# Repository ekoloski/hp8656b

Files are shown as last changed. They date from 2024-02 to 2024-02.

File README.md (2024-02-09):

## HP1820-3618 replacement

This project aims to use modern hardware to recreate the functionality of a mask rom microcontroller known as 1820-3618 in HP catalogs. It was used in the HP 8656B Signal Generator, and possibly other equipment, to interface the generators main cpu with both the fractional-n divider asic and various modulation circuits. It's a serial to parallel converter that also manages some gpio control lines.

The service manual describes a high level overview of the chips functions but lacks enough detail to create a suitable replacement. As I later found out, this firmware also does a couple of interesting things in response to a few serial commands I've never seen my 8656B issue. It also provides some routines for troubleshooting the rest of the circuitry.

### But...why go to the effort when you can just get one from a junk unit?

I purchased this signal generator on one of the auction sites with the understanding that it was for parts only and needed repair. My goal from the start was to restore the unit and use it as part of my electronics lab. After quite a bit of debugging I ultimately traced the issues to a failing adjustment potentiometer and a failed transistor. This is where the story should happily end, however it does not. In the course of troubleshooting I did some sloppy probing around A13U9 which led to the introduction of **-15V** to the 'Out of Lock' comparator output pin, which is directly connected to pin 11 of the 1820-3618, A13U28.

The chip never functioned properly after that event. The unit was not able to achieve PLL lock even after the original faults were discovered and repaired. I probed the serial input of A13U28 and found data. I then probed the 4 parallel output pins and the control lines, still no activity.

I was unable to find any information on this chip, labeled as a Motorola SC87336CP. Comparing the pinout in the 8656B service manual I found it to be fairly unique pinout in the world of Motorola 8bit microcontrollers of the time. Some educated guesses led me to the MC68705P5, which fit the description. I suspect that my chip is a mask rom variant of this microprocessor. Which is great, but without the ability to read the ROM I am still stuck.

Thinking that it was a lost cause to recreate the chip at this point I decided to purchase a second 8656B in much worse cosmetic condition. The part was harvested, transplanted, and the repaired unit works great. Everything should have been wonderful! Unfortunately I decided to investigate what in addition to a missing A13U28 was wrong with the donor unit. Much to my disappointment, the only problem was a faulty electrolytic capacitor. Of course I had to replace it but now I'm back to the start and stuck with an otherwise functional boat anchor in need of one unobtanium chip.

### Extracting the ROM

After quite a bit of reading I had come to the belief that the chip would need to be carefully decapped and photographed under a microscope. It could then be possible to locate the ROM on the die and optically recover the bits. I've seen it done on the internet, so it's got to be easy, right?

Probably not. So I shelved this project in lieu of some others and spent a while just not thinking about it. Then I did a little more research and came across the work by [Sean Riddle](http://seanriddle.com/mc68705p5.html). He details an obscure operating mode of the same family of CPU, and how he exploited it.

This mode is entered by powering the chip with /RESET /INT and TIMER high, and pulling PC0 high to 7.5V. When the micro comes out of reset it will ingest opcodes to execute from PortA. At the same time, an output is latched onto PortB. If the instruction on PortA happens to be 0x9d (nop) then the chip will simply continue to iterate through all 2K of it's address space. The output on PortB is a permutation of the current address, and the contents in memory. There is also apparently some data on PortC, but that's damaged on my chip so I didn't bother. I suspect it's the missing bits of the address.

As mentioned, the damage to my chip was conveniently located on PortC. Maybe there's hope that this method works on my particular mask rom, and that it's not too badly damaged? I figured it's worth a shot, so I breadboarded everything up and hooked up the scope.

To my amazement, there was data. A stream of it! The byte is sampled on the falling edge of each clock, 8 clocks are required to produce one byte of actual data, as it appears in the form of:
    {ADDR} {ADDR} {DATA} {DATA} {ADDR} {ADDR} {DATA} {DATA}

I noticed that the pattern was repeating at each 16K boundary, meaning we have a 2K address space. The chip will happily loop through and read out the address space until reset.

A healthy chunk of data was captured on the logic analyzer. The data was sifted from the noise to produce a raw dump.

### Interpreting the ROM

Next I needed to figure out what I was looking at. Nothing lined up with the memory mapping from the MC68705P5's datasheet. I realized that not only did the chip fetch an opcode from PortA, it fetched an address. The 0x9D must have been read in as $59D, meaning my capture started at 1437 bytes in! I shifted the data to realign it and it lined up perfectly with the memory map in the datasheet. I overwrote all non-ROM addresses with 0x9D to make disassembly easier and was ready to disassemble.

The [MAME project](https://www.mamedev.org/) has done a lot of work with this type of micro, and it's no surprise they have a nice disassembler called unidasm, which happily ingested the ROM from my crippled chip.

It took a moment and help from the Motorola M68HC05 Applications Guide, but I was able to wrap my head around the result. The only code I've written for microprocessors has been interrupt driven and was written in C. This is neither of those things. Instead it's beautify simple and elegant.

Beyond that, recreating the functionality of the chip be considerably more difficult without it. There are nuances that are not discussed in the service manual. I've also found that a test pin labeled as unused in the service manual does have a routine associated with it. Perhaps this chip was used in other equipment?

### Converting to something more modern

Now that I have the program from the chip and it's datasheet there's no reason not to create a modern replacement.

I decided on an Atmel ATMEGA32U4-MUR. It was available, came in a small enough package that I could build a board to fit the original DIP-28W, and had more than enough capability for the job. After creating a small breakout board and soldering pin headers to emulate the original DIP28W, I was ready to start adapting the program.

With how purpose built the code is, and with the role it plays in setting up things like the FM calibration and other support circuitry in the 8656B, I suspect that the timings involved may be somewhat critical. I likely wouldn't achieve anything as close to the original if I wrote it in C, unless I did a bunch of extra work. So, AVR8 it is.

### Again...why?

The chances of anyone else needing a replacement for an HP1820-3618 are pretty slim. The chances of finding this and needing a replacement? Negligible.

But I would bet that there are others who may find themselves, for whatever reason, wanting to get a peek into a similar mask rom. I'd be glad if it helps in that case and maybe even resurrects some piece of hardware. It's been a lot of fun, and I've rediscovered a bit of code that, in all likelihood, no one else has even looked at in at least the last 25 years.

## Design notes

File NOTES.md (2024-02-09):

**8656B Notes**

## Clock considerations
The 68705P5 internal clock generator prescales the oscillator input by four. A 4MHz AT cut parallel resonance crystal at about 27pF is populated on the 8656B, meaning that the microcontroller will run at a clock frequency of 1MHz.

The 32U4 does have an internal prescaler on it's oscillator input, however this one is a divide-by-8. Fortunately most instructions run a little quicker in AVR so the timings are not too far off. Consideration should be taken when calculating delays.

## Fractional N Microprocessor
Various notes about this thing. In general it slurps up (up to) 17 bytes of serial information. It digests the first byte as a command and actuates a number of control lines in response. The main functionality is to convert this 16 bytes of data into 4 bit chunks spit out of it's parallel port.

### Serial Data Input
  - Serial data is sampled on rising edge of clock pulse and is sent in 4-bit words. Data always begins with a 4-bit command to this microcontroller. Commands are listed below. If the command is 0x8 or higher, 16 words of 4-bit data are expected to follow. 

### Serial Commands

The command is the first byte received on the serial line and directs the microprocessor to actuate
different modes on it's output. For example, enable FM mode.

  |Command|Description|
  |---|---|
  |0x00|Set `fm_dc_en` and update the controller ? |
  |0x01|Send status of PLL Out of Lock indicator, used in built-in self test mode `6` (Press Shift+INCR SET to enter test mode) |
  |0x02|Disable FM|
  |0x03|Enable FM|
  |0x04|Enable FM DC Mode|
  |0x05|FM Calibration Cycle|
  |0x08|Standard transmit - sends data to Fractional-N controller - last byte is a **0x04**|
  |0x09|Alternate transmit - last byte is a **0x08**|
  |0x0A|Alternate transmit - last byte is a **0x09**|

### Signals (Pin Registers as they are on the 68705P5)
  - PA0:3 Parallel Data Out
  - PA4 : Parallel Clock Out
  - PA5 : Data Valid Output
    - Typically a 7.2uS positive pulse, otherwise low
  - PA6 : FM DC Enable
  - PA7 : FM Offset
  - PB0 : FM Enable
  - PB1 : B+C (H) Blank/Compare Out
  - PB2 : S (L)
  - PB3 : FM Cal Add Cycle
  - PB4 : (Test Mode Input) FM No Calibration
  - PB5 : (Test Mode Input) LF Loop set to 66.80001MHz
  - PB6 : (Test Mode Input) Signal Analysis Test Mode
  - PB7 : (Test Mode Input) Unused
  - PC1 : Serial Data Input
  - PC2 : Mode Select Input
    - Normal operation: High
    - Test mode: Low
  - PC3 : PLL Out Of Lock Indicator
  - INT : Serial Clock In

### Signals (Pin Registers as they are on the 32U4)
  - PD0:3 Parallel Data Out
  - PD4 : Parallel Clock Out
  - PD5 : Data Valid Output
    - Typically a 7.2uS positive pulse, otherwise low
  - PD6 : FM DC Enable
  - PD7 : FM Offset
  - PB0 : FM Enable
  - PB1 : B+C (H) Blank/Compare Out
  - PB2 : S (L)
  - PB3 : FM Cal Add Cycle
  - PB4 : (Test Mode Input) FM No Calibration
  - PB5 : (Test Mode Input) LF Loop set to 66.80001MHz
  - PB6 : (Test Mode Input) Signal Analysis Test Mode
  - PB7 : (Test Mode Input) Unused
  - PF5 : Serial Data Input
  - PF6 : Mode Select Input
    - Normal operation: High
    - Test mode: Low
  - PF7 : PLL Out Of Lock Indicator
  - PC7 : Serial Clock In

### fuses:
  -  _lfuse_ **0xED** - Ext Crystal Osc, Freq 3.0-8.0MHz, 16KCK _ 4.1mS delay, /8 Divider
  -  _hfuse_ **0xD9** - Boot flash 2048, start $3800, JTAG disabled SPI Programming enabled
  -  _efuse_ **0xC8** - Brownout Detection 4.3V, HW Boot Enable=0
  -  _lock_  **0xFF** - No lock set

  - `avrdude -c dragon_isp -p m32u4 -P usb -U lfuse:w:0x6D:m`
  - `avrdude -c dragon_isp -p m32u4 -P usb -U hfuse:w:0xD9:m`
  - `avrdude -c dragon_isp -p m32u4 -P usb -U efuse:w:0xC8:m`
  - `avrdude -c dragon_isp -p m32u4 -P usb -U lock:w:0xFF:m`
  - `avrdude -c dragon_isp -p m32u4 -P usb -U flash:w:1820-3618.hex`

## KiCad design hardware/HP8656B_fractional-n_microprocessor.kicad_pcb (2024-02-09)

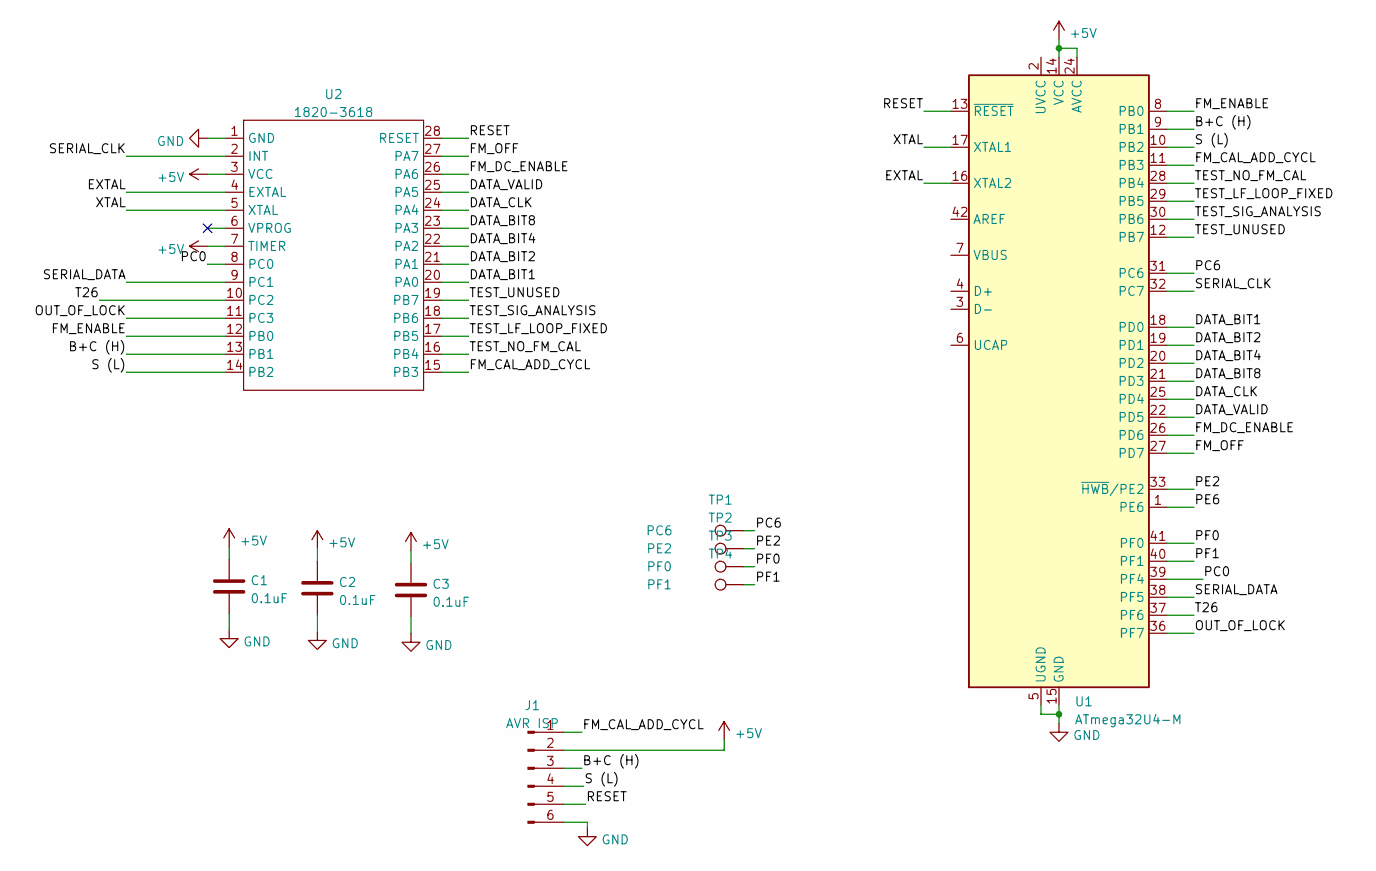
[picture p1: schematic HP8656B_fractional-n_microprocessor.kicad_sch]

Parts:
C1, C2, C3: 0.1uF; C_0603_1608Metric
J1: AVR ISP; PinHeader_2x03_P2.54mm_Vertical
TP1: PC6; TestPoint_Pad_D1.0mm
TP2: PE2; TestPoint_Pad_D1.0mm
TP3: PF0; TestPoint_Pad_D1.0mm
TP4: PF1; TestPoint_Pad_D1.0mm
U1: ATmega32U4-M; QFN-44-1EP_7x7mm_P0.5mm_EP5.2x5.2mm
U2: 1820-3618; DIP-28_W15.24mm_Socket

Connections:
+5V: C1.1, C2.1, C3.1, J1.2, U1.14 (VCC), U1.24 (AVCC), U1.34 (VCC), U1.44 (AVCC), U2.3 (VCC), U2.7 (TIMER)
/B+C (H): J1.3, U1.9 (PB1), U2.13 (PB1)
/DATA_BIT1: U1.18 (PD0), U2.20 (PA0)
/DATA_BIT2: U1.19 (PD1), U2.21 (PA1)
/DATA_BIT4: U1.20 (PD2), U2.22 (PA2)
/DATA_BIT8: U1.21 (PD3), U2.23 (PA3)
/DATA_CLK: U1.25 (PD4), U2.24 (PA4)
/DATA_VALID: U1.22 (PD5), U2.25 (PA5)
/EXTAL: U1.16 (XTAL2), U2.4 (EXTAL)
/FM_CAL_ADD_CYCL: J1.1, U1.11 (PB3), U2.15 (PB3)
/FM_DC_ENABLE: U1.26 (PD6), U2.26 (PA6)
/FM_ENABLE: U1.8 (PB0), U2.12 (PB0)
/FM_OFF: U1.27 (PD7), U2.27 (PA7)
/OUT_OF_LOCK: U1.36 (PF7), U2.11 (PC3)
/PC0: U1.39 (PF4), U2.8 (PC0)
/PC6: TP1.1, U1.31 (PC6)
/PE2: TP2.1, U1.33 (~HWB/PE2)
/PE6: U1.1 (PE6)
/PF0: TP3.1, U1.41 (PF0)
/PF1: TP4.1, U1.40 (PF1)
/RESET: J1.5, U1.13 (~RESET), U2.28 (RESET)
/S (L): J1.4, U1.10 (PB2), U2.14 (PB2)
/SERIAL_CLK: U1.32 (PC7), U2.2 (INT)
/SERIAL_DATA: U1.38 (PF5), U2.9 (PC1)
/T26: U1.37 (PF6), U2.10 (PC2)
/TEST_LF_LOOP_FIXED: U1.29 (PB5), U2.17 (PB5)
/TEST_NO_FM_CAL: U1.28 (PB4), U2.16 (PB4)
/TEST_SIG_ANALYSIS: U1.30 (PB6), U2.18 (PB6)
/TEST_UNUSED: U1.12 (PB7), U2.19 (PB7)
/XTAL: U1.17 (XTAL1), U2.5 (XTAL)
GND: C1.2, C2.2, C3.2, J1.6, U1.5 (UGND), U1.15 (GND), U1.23 (GND), U1.35 (GND), U1.43 (GND), U1.45 (GND), U2.1 (GND)

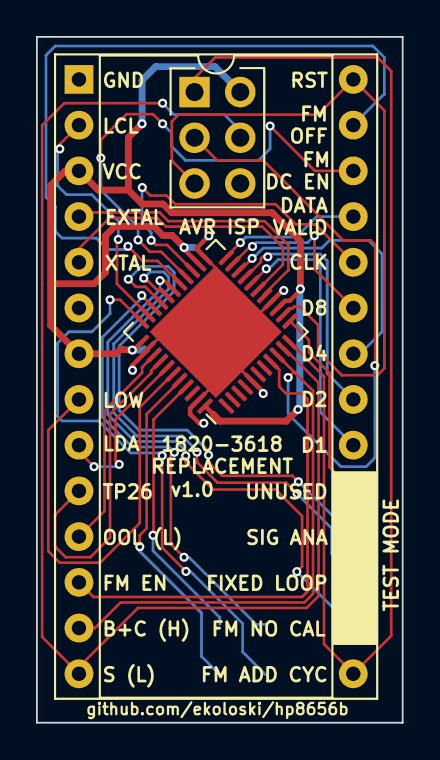
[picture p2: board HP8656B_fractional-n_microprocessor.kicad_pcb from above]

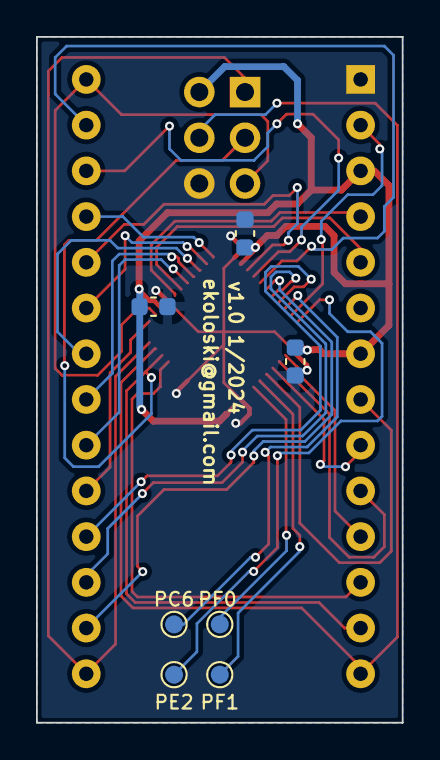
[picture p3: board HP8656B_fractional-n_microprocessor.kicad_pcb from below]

Board: 2 copper layers, 20.3 x 38.1 mm, 10 parts (7 on the bottom side), 30 nets.

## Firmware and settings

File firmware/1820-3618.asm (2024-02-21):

; Modern replacement for HP 1820-3618 _fractional-n microprocessor_ using an _ATMEGA32U4_
; 
; Copyright 2024 Edward Koloski <ekoloski@gmail.com>
; Licensed under MIT (https://github.com/ekoloski/hp8656b/LICENSE)
;
; TODO: The basic functionality has been tested. Here is what still remains:
;  - Test and compare the fixed loop mode against the original
;  - Verify any delays that have a TODO comment on them
;  - Verify that command 0 works as expected

    .include "m32U4def.inc"

    .dseg
    .org    SRAM_START
sStatus:
    .BYTE   1
sCommand:
    .BYTE   1
sBuffer:
    .BYTE   16
sDataType:
    .BYTE   1

    .cseg
    .org    0x00

init:
    ldi     r16,LOW(RAMEND)     ; initialize
    out     SPL,r16             ; stack pointer
    ldi     r16,HIGH(RAMEND)    ; to RAMEND
    out     SPH,r16             ;

    ldi     r16,0xFF            ;
    out     DDRD,r16            ; set PORTD PD0:7 Output
    ldi     r16,0x05            ;
    out     PORTB,r16           ; set PB0 `fm_en` and PB2`S_L` high
    ldi     r16,0x0F            ;
    out     DDRB,r16            ; set PB0:PB3 Output
    ldi     r16,0xF0            ; 
    out     PORTB,r16           ; Set pull-ups on test mode input pins PB4:7
    sbi     PORTC,7             ; set PC7 pull-up
    sbi     PORTC,6             ; set PC6 pull-up `TP26`

    sbis    PINF,6
    rjmp    test_mode_tp26      ; if PF6 `TP26` is low then jump to TP26 routine
    rjmp    main                ; otherwise proceed to main program

test_mode_tp26:
    sbis    PINB,5                          ; if PB5 `Test mode fixed loop` is LOW
    jmp     testmode_lf_loop_vco_fixed      ;  jump to fixed loop routine
    sbis    PINB,6                          ; if PB6 `Signal Analysis` mode is LOW 
    jmp     testmode_signature_analysis     ;  jump to sig ana routine
    sbis    PINB,7
    jmp     testmode_unused                 ; if PB7 `Unused` is LOW jump to unused test routine
                                            ; Service manual lists as unused, but it jumps into
                                            ; signal analysis at an alternate point.
    rjmp    test_mode_tp26                  ; We're stuck here until a test mode is selected

main:
; Goofing off while testing
; Nothing uses the parallel bus most of the time, so I am using this idle time and the data 
; bits to output the last command run. This is displayed on a 7segment LED on the breadboard.
;    ldi     XL,LOW(sCommand)
;    ldi     XH,HIGH(sCommand)
;    ld      r16,X
;    out     PORTD,r16

    ldi     XL,LOW(sCommand)    ; initialize X pointer
    ldi     XH,HIGH(sCommand)   ; to SRAM array address
    ldi     r16,0x10            ;
buffer_fill_loop:
    st      X+,r16              ; Initialize the buffer (17 bytes) with all 0x10s 
    cpi     XL,Low(sBuffer+17)  ; Done yet?
    brne    buffer_fill_loop    ;
                                ;
                                ;Serial data is valid on the falling edge of the clock.
                                ;The first 4-bit word is always a command to this chip followed
                                ; by a 70uS wait, to allow the Fractional-N Controller time
                                ; to receive a Cycle Start Pulse.
                                ;The next 16 4-bit words are data words
    ldi     XL,LOW(sCommand)    ;
    ldi     XH,HIGH(sCommand)   ;
    ld      r16,X               ; Load the first word from the buffer and wait to receive
receive_command:
    sbic    PINC,7
    rjmp    receive_command     ; wait for PC7 `SCL` to go low
    sbis    PINF,5              ; 
    clc                         ; funny little dance
    sbic    PINF,5              ; to get the data bit into the carry bit
    sec                         ;
    rol     r16                 ; rotate the byte through carry to store the bit
                                ;  It's cooler in m6805 due to the indexed address mode on rol    
command_clockwait:
    sbis    PINC,7
    rjmp    command_clockwait   ; wait for PC7 `SCL` to go high
    brcc    receive_command     ; Loop to receive the word
    st      X,r16
    sbrs    r16,3               ; check if command is 0-7 and go run it
    rjmp    command_parser      ; otherwise loop to receive 16 more 4-bit words
    ldi     XL,LOW(sBuffer)
    ldi     XH,HIGH(sBuffer)
    ld      r16,X
receive_word:
    ld      r16,x
receive_bits:
    sbic    PINC,7
    rjmp    receive_bits        ; wait for PC7 `SCL` to go low
    sbis    PINF,5
    clc                         ; Transfer to carry
    sbic    PINF,5
    sec
    rol     r16                 ; rotate in the bit
rx_clockwait:
    sbis    PINC,7
    rjmp    rx_clockwait        ; Wait for the clock to go high
    brcc    receive_bits        ; make sure the entire word was received
    st      X+,r16              ; store it
    cpi     XL,Low(sBuffer+16)  ; check if all 16 bytes have been received
    brne    receive_word

command_parser:
    ldi     XL,LOW(sCommand)    ; initialize X pointer
    ldi     XH,HIGH(sCommand)   ; to Command address in SRAM
    ld      r16,X               ; load it
    cpi     r16,0x00
    breq    command_0           ; Command 0
    cpi     r16,0x01
    breq    command_1           ; Command 1
    cpi     r16,0x02
    breq    command_2           ; Command 2
    cpi     r16,0x03
    breq    command_3           ; Command 3
    cpi     r16,0x04
    breq    command_4           ; Command 4
    cpi     r16,0x05
    breq    command_5           ; Command 5
    cpi     r16,0x08
    breq    command_8           ; Command 8
    cpi     r16,0x09
    breq    command_9           ; Command 9
    cpi     r16,0x0A
    breq    command_a           ; Command A
    jmp     main                ; Not a valid command. Jump back to the start and try again

command_0:                      ; Not entirely sure what this one is for. 
                                ; It seems to preserve PORTD but set `data_valid`
                                ; Then send a a control, or terminate, word to the 'N Controller
    ldi     r16,0x00            ; load 0x00 into r16
    ldi     XL,LOW(sStatus)     ;
    ldi     XH,HIGH(sStatus)    ;
    ld      r17,X               ; load sStatus into r17
    or      r16,r17             ; or r16 and sStatus
    ldi     XL,LOW(sBuffer+15)  ;  ** Should this be sDataType or the last word in sBuffer? **
    ldi     XH,HIGH(sbuffer+15) ;
    st      X,r16               ; store it into the last word
    call    tx_last_word        ; transmit the last word
    jmp     main                ; all done
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

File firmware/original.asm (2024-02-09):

          ; HP 1820-3618 Mask ROM based off MC68705P5 (Or so I think)
          ; $000=PORTA, $001=PORTB, $002(low 4 bits)=PORTC, $003 not used
          ; $004=DDRA,  $005=DDRB,  $006(low 4 bits)=DDRC,  $007 not used (DDRs read as $FF)
          ; $008=Timer Data Reg, $009=Timer Control Reg
          ; $00A-$03F not used
          ; $040-$07F=RAM (stack starts at $07F)
            ; $40=status byte
            ; $41=command word
            ; $42-$52=buffered serial data
          ; $080-$0FF=Page Zero User ROM
          ; $0AC-$3BF not used
          ; $3C0-$664 Main User ROM
          ; $665-$783 not used
          ; $784-$7F7 Self-Check ROM
          ; $7F8-$7F9 Timer Interrupt Vector
          ; $7FA-$7FB External Interrupt Vector
          ; $7FC-$7FD SWI Vector
          ; $7FE-$7FF Reset Vector

          *ZERO-PAGE USER ROM
          ORG $80

00000080: a6 ff     lda   #$FF          ;
00000082: b7 04     sta   $04           ;set PORTA output
00000084: a6 80     lda   #$80          ;
00000086: b7 00     sta   $00           ;set PA7 (fm_off) high
00000088: b7 40     sta   $40           ;
0000008a: a6 0f     lda   #$0F          ;
0000008c: b7 05     sta   $05           ;set PB0:PB3 output
0000008e: a6 05     lda   #$05          ;
00000090: b7 01     sta   $01           ;set PB0 and PB2 `fm_en` and `S (L)` high
00000092: a6 00     lda   #$00
00000094: b7 06     sta   $06           ;set PORTC input

                                        ; Check test mode `TP26` is low
00000096: 05 02 03  brclr 2, $02, $09C  ;if PC2 `TP26` is low branch and check which mode to run
00000099: cc 03 c0  jmp   $03C0         ;else jump to the main program

0000009c: 0a 01 03  brset 5, $01, $0A2  ;if PB5 `TEST MODE FIXED LOOP` is low
0000009f: cc 05 b3  jmp   $05B3         ;jump to $5B3 [Test Mode Fixed Loop]

000000a2: 0c 01 03  brset 6, $01, $0A8  ;if PB6 (TEST MODE SIG ANA) is low
000000a5: cc 05 f0  jmp   $05F0         ;jump to $5F0 [Test Mode SIG ANA]

000000a8: 0e 01 f1  brset 7, $01, $09C  ;if PB7 (TEST MODE UNUSED) is low
000000ab: cc 06 64  jmp   $0664         ;jump to $664 [Test Mode UNUSED]
          ; Service manual lists this as unused but it jumps into an alternate point of sig analysis

          *USER ROM
          ORG $3C0                      ; [Main program start]
                                        ;Also, interrupt vectors if they were unmasked
000003c0: ae 41     ldx   #$41          ;start at address $41
000003c2: a6 10     lda   #$10          ;
000003c4: f7        sta   ,x            ;
000003c5: 5c        incx                ;
000003c6: a3 52     cpx   #$52          ;
000003c8: 26 fa     bne   $3C4          ;
                                        ;loop to fill 17 bytes of Buffer $41:$52 with 0x10
                                        ; placing a marker at bit at the end of the high nibble

                                        ; Receive the first byte of serial data (the command)
000003ca: 2f fe     bih   $3CA          ;
000003cc: 2f fc     bih   $3CA          ;wait until the clock pin is low, twice for debounce
000003ce: 02 02 00  brset 1, $02, $3D1  ;test the Serial Data Input pin and store result in carry
000003d1: 39 41     rol   $41           ;rotate left through carry $41
                                        ;   This is really elegant!
000003d3: 24 f5     bcc   $3CA          ; Check if entire command is received
                                        ;
000003d5: 07 41 11  brclr 3, $41, $3E9  ;jump to the command parser unless TX command is received
                                        ;otherwise received the next 16 words

                                        ; Receive the next 16 bytes of data
000003d8: ae 42     ldx   #$42          ;index register to $42 - start of data words
000003da: 2f fe     bih   $3DA          ;
000003dc: 2f fc     bih   $3DA          ;wait until the clock pin is low, wice for debounce
000003de: 02 02 00  brset 1, $02, $3E1  ;test the Serial Data Input pin and store result in carry
000003e1: 79        rol   ,x            ;rotate X left thru carry
000003e2: 24 f6     bcc   $3DA          ;check if the whole word is received
000003e4: 5c        incx                ;increment to the next word
000003e5: a3 52     cpx   #$52          ;check if all 16 words are received
000003e7: 26 f1     bne   $3DA          ; loop for all 17 bytes

                                        ; [Command Parser]
                                        ;Determine which command was received and run it
000003e9: b6 41     lda   $41           ;load $41 into A
000003eb: a1 00     cmpa  #$00          ;compare A with 00
000003ed: 27 22     beq   $411          ;jump to $411 if equal
000003ef: a1 01     cmpa  #$01          ;compare A with 01
000003f1: 27 29     beq   $41C          ;jump to $41C if equal
000003f3: a1 02     cmpa  #$02          ;compare A with 02
000003f5: 27 3c     beq   $433          ;jump to $433 if equal
000003f7: a1 03     cmpa  #$03          ;compare A with 03
000003f9: 27 3c     beq   $437          ;jump to $437 if equal
000003fb: a1 04     cmpa  #$04          ;compare A with 04
000003fd: 27 3c     beq   $43B          ;jump to $43B if equal
000003ff: a1 05     cmpa  #$05          ;compare A with 05
00000401: 27 49     beq   $44C          ;jump to $44C if equal
00000403: a1 08     cmpa  #$08          ;compare A with 08
00000405: 27 4d     beq   $454          ;jump to $454 if equal
00000407: a1 09     cmpa  #$09          ;compare A with 9
00000409: 27 4d     beq   $458          ;jump to $458 if equal
0000040b: a1 0a     cmpa  #$0A          ;compare A with 0A
0000040d: 27 4d     beq   $45C          ;jump to $45C if equal
0000040f: 20 57     bra   $468          ;jump to $468

                                        ; START OF COMMANDS
                                        ;The service manual does not explain these

                                        ; [Command 00] Unsure when this is called
                                        ;It preserves PORTA and sets `fm_dc_en`
00000411: a6 00     lda   #$00          ;
00000413: ba 40     ora   $40           ;
00000415: b7 52     sta   $52           ;
00000417: cd 05 4f  jsr   $054F         ; Transmit terminate word to N controller [tx_last_frame]
0000041a: 20 4c     bra   $468          ;jump back to program start
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
